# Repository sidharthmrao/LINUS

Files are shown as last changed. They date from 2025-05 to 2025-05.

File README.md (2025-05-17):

# LINUS
“Linus” is a 2D-drawing machine which uses a marker to draw inputted images in the one-line-drawing art style!  
  
[Project Website](https://sidharthmrao.github.io/LINUS/index.html)  
  
### Directory Structure
#### cad
Contains CAD step files.

#### docs
Contains files for the project website.

#### exp
Contains experimentation files for image processing and pathfinding.

#### input
Contains input images

#### lib
 - graph.py - Contains graph datastructures and algorithms
 - render.py - Tools for Pygame rendering
 - serial_com.py - UART communication between Host device and microcontroller
 - skeleton.py - Image processing and skeletonization
 - slicer.py - Optimal path construction

#### pico
 - Contains files to run on the Raspberry Pi Pico for printer control and communication

#### config.py
 - Configuration file, select input image, activate debug mode, etc.

### Running Locally
To run locally, create a Python 3.13 environment using the `requirements.txt`.  
Edit `config.py` as necessary.   
Source it and then run `main.py`.

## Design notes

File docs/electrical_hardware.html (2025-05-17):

LINUS Slicer Electrical Hardware Mechanical Hardware Project Repo (https://github.com/sidharthmrao/LINUS)

LINUS - Microcontrollers (ECE 4760) Final Project - Electrical

# System Overview

Electrically, the system was comprised of six parts:

- 1 Raspberry Pi
- 1 Pico
- 2 Stepper Motor Drivers
- 2 Stepper Motor

Information travels mostly in one direction, from the Pi to the motors, except for the duplex line between the Pico and Pi. We designed our system to minimize interconnectivity in order to make debugging and integration easier. For example, we chose stepper motors because they could do open-loop position control very precisely.

# System Diagram

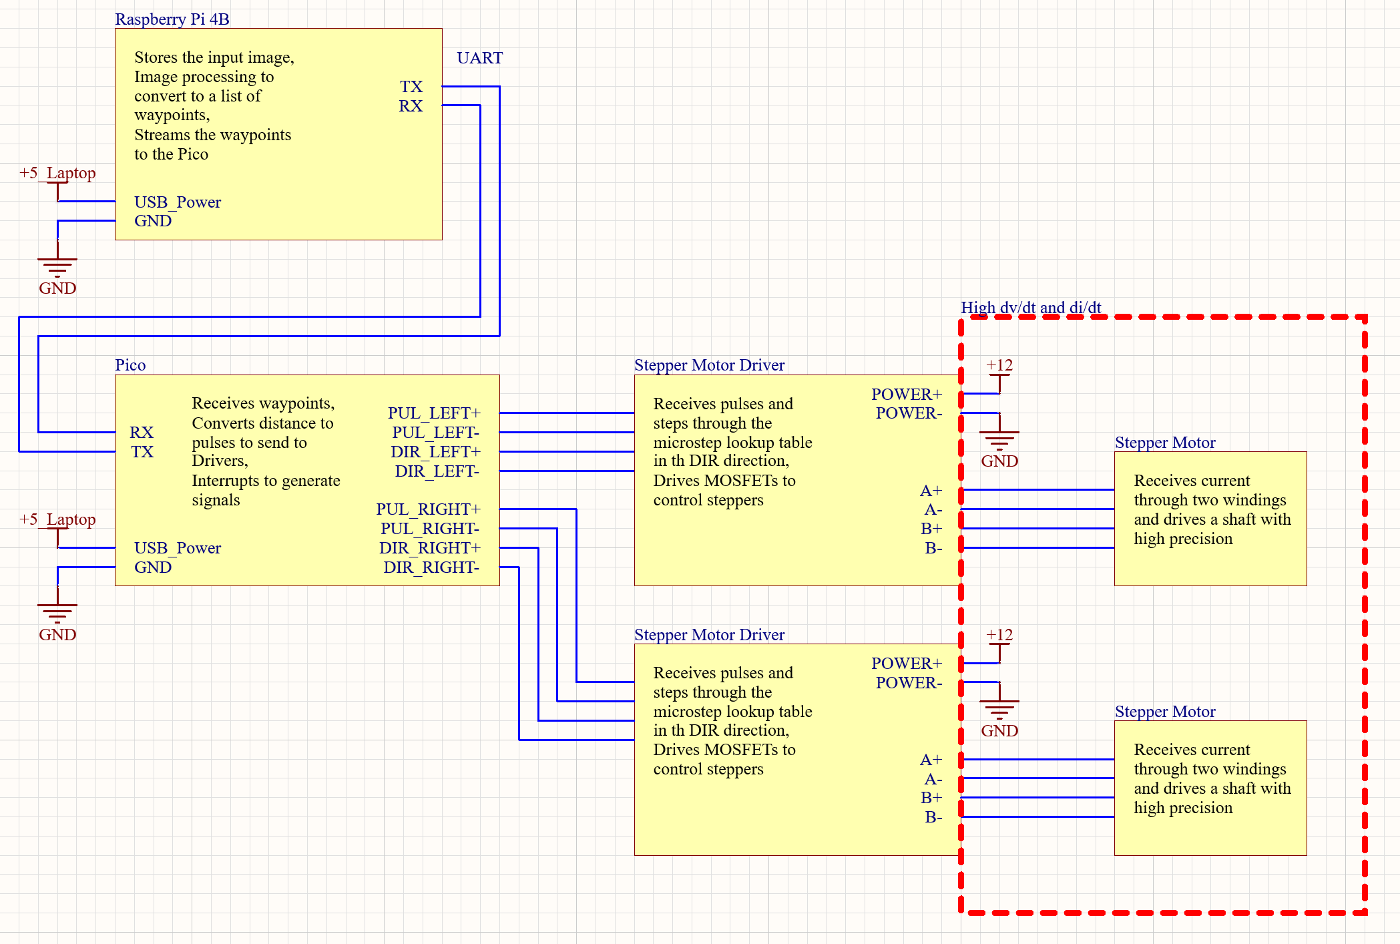
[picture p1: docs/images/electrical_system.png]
Electrical System Schematic of LINUS


# Detailed Technical Description

## Raspberry Pi

LINUS starts at the Pi. Here, the input image is stored and input into the slicer. The slicer takes the image and processes it to create a list of waypoints stored as pixel values on a 480x480 grid. Details about how the Pi turns a general image file into this list can be found in Slicer page.

This list of waypoints represents a list of position setpoints for the stepper motors to get to. The waypoints are densely populated along the planned path so that there is a small distance between each waypoint. This small level of subdivision allows us to paint smooth curves with the stepper motors.

### UART Communication

Now that the Pi has the list of waypoints to send to the Pico, it opens up a serial communication connection with the pico. UART is a full-duplex communication protocol that uses a TX, RX, and GND line to send bits between two devices. UART doesn't use a controller-peripheral architecture, unlike other common communication protocols such as I2C, SPI, and CAN. The Pi and Pico can communicate with each other independently. In our system, we sent strings over UART and parsed them on the receiving end.

Once the UART line is up, we poll the RX line on the Pi to see if the Pico has sent a “READY” string, signaling that it is capable of receiving and executing a waypoint. If so, the Pi will send a waypoint “(X, Y)” over to the Pico. It will then continue polling the line until either the Pico sends “READY” again or the Serial object disconnects.

For debugging purposes, the Pi can also generate an animation of how the Pico would draw the list of waypoints through a pygame window.

## Pico

The Pico is responsible for receiving waypoints from the Pi and outputting PUL and DIR signals to the two stepper motor drivers to move the motors. In this project, we decided to use stepper motors and open-loop control for simplicity in design.

The pico stores two stepper motor structs that store information about configuration (max velocity, GPIO pins) and current state (current position, target position, current velocity).

### Core 1

This core is responsible for communication with the Pi. We needed to use both cores because we have interrupts that generate pulses to the stepper motor driver, and each pulse is generated by one interrupt call. Since our high-precision application required microstepping, we would send thousands of pulses per second to the stepper motor drivers, which would be interrupted by UART writes and reads.

The core begins by initializing the UART peripheral and the motor target positions. Each motor controls movement along one axis, so one motor gets one setpoint along the x-axis, and the other motor gets a setpoint along y.

Then, the core enters its main loop, where it will continuously poll both motors' current and target positions. When one motor reaches its target position, the core will write “READY” to the UART line, signaling to the Pi that the Pico wants to receive a waypoint. It will then read from its UART RX line for the waypoint “(X, Y)” and store those values into the targeted positions for the X motor and Y motor.

It will then go back to checking if the motors have reached their target positions and continue the loop.

### Core 0

Core 0 is responsible for interfacing with the stepper motor drivers. In this dual-core architecture, each variable is only written by one core, so there are zero risks of race conditions. We designed the motor structs this way so that we wouldn't have to worry about multithreading debugging, and so that the behavior of one core is completely decoupled from the behavior of the other.

After initializing GPIO and core 1, core 0 jumps into its main loop. Here, the Pico will check if the current position matches the target position for each motor. If not, it will set the DIR pin to its required state, and bring the PUL pin high. If the current position matches the target position, it won’t set the PUL pin high.

After setting the DIR and PUL pins of both motor drivers to their proper states, core 0 will sleep for 5 microseconds. This is the pulse width. The stepper motor drivers use pulse frequency modulation, and this will be covered in depth in the “Stepper Motor Drivers and Stepper Motors” section coming up.

After sleeping for the pulse width, core 0 will check if the PUL pins are high, and if they are, it will set them low and increment the current position of that motor. It will then sleep for 1200 microseconds, which is the distance between the pulses. This means our pulse frequency is actually fixed, so we only drive the stepper motors at 0, - max_velocity, or +max_velocity.

### The Beauty + Importance of System Simplicity

While it might seem crude to make a system that only drives at three speeds, this was the simplest option out of the many that we successfully implemented. We originally had a system that would generate pulses using interrupts. Each interrupt call would set its own hardware alarm timer to a specific value depending on the desired motor speed (proportional to pulse frequency). This would allow us to drive both motors at different speeds, and we could precisely control the speed.

We also implemented acceleration clamps, which would prevent the motor from accelerating too quickly and slow down the motor as it approached a waypoint. We did this because we wanted a smooth motion through waypoints, and we were concerned that the momentum of the rails would cause the stepper motors to stall when accelerating.

As we tested the system, we raised the acceleration clamps higher and higher until they were functionally not doing anything. Even if the motors instantaneously went from 0 to maximum speed, they still didn't stall, so we removed the code.

Since the motors didn't need the acceleration clamps, they only needed to be able to drive at three speeds. We thus removed those features and the interrupts as well, and rewrote the software in a simpler fashion to improve long-term maintainability and readability, especially since this code may be public for others to read after our project is published.

## Stepper Motor Drivers and Stepper Motors

The Stepper Motor Drivers receive data signals to move from the Pico, and output power signals to the motors to move them. The driver needs two pins to do this: PUL and DIR. DIR will tell the driver which way to turn the motor, and PUL will tell the driver to step once in the DIR direction. We can decide the microstepping resolution of the driver and set it to any multiple of two between 1 and 32. Stepper motors have 100 magnetic poles or 50 pole-pairs on the rotor. They also have two independent windings in the stator that control the rotor.

If you can only drive each winding off, full in one direction, and full in the other direction (with an H-bridge), then you are full-stepping. The full-stepping resolution of a stepper motor is 200 steps per revolution. By microstepping, you drive one winding at less-than-full voltage by PWM-ing on the H-bridge.

The stepper motor driver is able to do a microstepping resolution of 32, which allows us to do 200 * 32 = 6400 pulses per revolution. Internally, the stepper motor driver does this by storing an array 6400 elements long called the microstep lookup table. Each time a falling edge is detected on the PUL input line, the driver increments through the lookup table some amount. If the microstepping resolution is 32, then the driver will increment one position through the array. If the microstepping resolution is 1, then the drive will increment 32 positions through the array. The array contains the PWM duty cycle of the A and B windings. This value gets scaled by the motor drive strength, and then that value is directly sent to the PWM module and gate drivers of the MOSFETs. The DIR pin decides which direction the driver should step through its lookup table.

Changing the PWM duty cycles of the A and B windings of the motor will change the amount of current traveling through them. This modulates the direction of the magnetic field that the rotor sees, and if the rotor’s own permanent magnet field is not aligned with the stator windings' field, then a torque will be applied to the shaft to move it to where the windings want the rotor to be.

Each time the PUL pin is pulsed, the stators magnetic field changes by some position. If the PUL pin is not pulsed, the winding currents will not change, and the rotor will remain in its place. By sending pulses at a specific frequency, the magnetic field position will change at a specific rate. This means that if we control the driver using PFM, then the PFM is modulating the motor's speed, which is very different from other motor applications, where the current is modulating the motor's torque. This unique feature of stepper motors allows us do open-loop position control with very high precision. 6400 pulses per revolution means we can move LINUS's pen with a precision of <0.001 inches.

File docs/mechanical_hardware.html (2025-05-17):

LINUS Slicer Electrical Hardware Mechanical Hardware Project Repo (https://github.com/sidharthmrao/LINUS)

LINUS - Microcontrollers (ECE 4760) Final Project - Mechanical Hardware

# Mechanical Design

The mechanical design for LINUS was largely inspired by the structure of low-cost 3D printers. We chose a belt drive system for its simplicity, affordability, and ease of implementation. The core frame is constructed using two aluminum T-slot extrusions: one 40x20mm and one 20x20mm. The 40x20 T-slot serves as the main X-axis rail, along which the 20x20 T-slot (Y-axis) is mounted. The drawing head (pen holder) moves along the Y-axis, enabling the machine to reach any point within its working area.

Motion in both axes is powered by stepper motors driving timing belts. On each axis, the belt loops through the central slot in the T-slot rail, connecting to a motor pulley at one end and an idler pulley at the other. The idler pulley maintains belt tension and alignment to prevent skipping. Getting the belt routing and tensioning system to work reliably required several rounds of iteration.

## Mechanical Components

X-axis Mounting Plate (motor)
This component anchors the X-axis stepper motor. The motor bolts to the vertical plate, while the 40x20 T-slot rail fits into the rectangular cutout and is secured in place via bolts. This sliding mount allows for adjustable belt tensioning by loosening the blots, shifting the assembly outward, and then re-tightening.

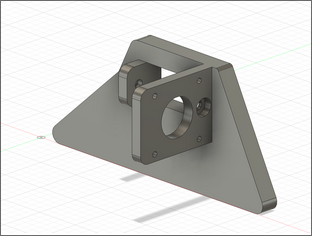
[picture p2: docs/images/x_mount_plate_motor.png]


X-axis Mounting Plate (motor)

X-axis Mounting Plate (idler pulley)
This is the matching plate on the opposite side of the X-axis. It houses the idler pulley, implemented as a bearing press-fit into the mount. The T-slot rail passes through just like on the motor side, and the same sliding method can be used to apply tension to the belt.

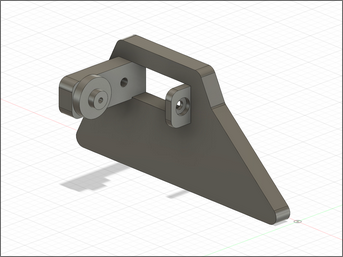
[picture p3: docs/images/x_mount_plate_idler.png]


X-axis Mounting Plate (idler pulley)

Y-axis Mounting Plate (x2)
The two identical plates support the Y-axis rail and connect it to the X-axis motion system. These plates mount to and sandwich the Y-axis rail as well as the bearings or wheels that allow it to slide along the X-axis. This provides smooth motion and stability for the Y-axis rail. Additionally, the belt is routed through the rectangular slots in these plates and glued down to secure it.

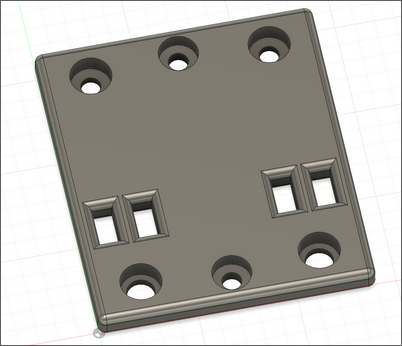
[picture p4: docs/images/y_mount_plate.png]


Y-axis Mounting Plate

Y-axis Motor Mount
This mount holds the Y-axis stepper motor in place and aligns its shaft with the belt path. Like the X-axis motor mount, it attaches to the 20x20 T-slot rail and allows for belt tensioning through a simple sliding mechanism.

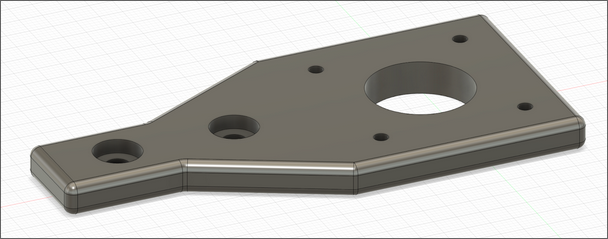
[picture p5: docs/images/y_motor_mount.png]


Y-axis Motor Mount

Y-axis Idler Pulley Mount
Located on the opposite end of the Y-axis rail, this mount holds the idler pulley bearing. It works just like the X-axis version, with a press-fit bearing and a sliding design to adjust tension as needed.

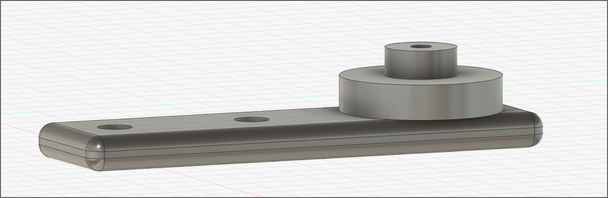
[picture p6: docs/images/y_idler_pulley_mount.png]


Y-axis Idler Pulley Mount

Idler Pulley Half (x2)
These circular components complete the idler pulley assemblies. They press-fit onto the other side of the bearing (the side not already fitted onto the axes), This forms a low-friction guide with an outer lip to prevent the belt from slipping off.

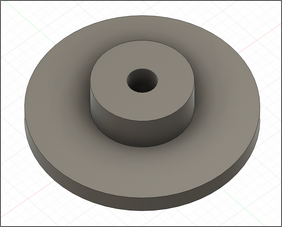
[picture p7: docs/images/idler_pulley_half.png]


Idler Pulley Half

Pen Holder
The pen holder grips the drawing tool (marker) and is mounted to the Y-axis carriage, which in turn moves along the X-axis. It includes a set screw to hold the marker firmly in place while minimizing play. The holder also serves as a termination point for the Y-axis belt, using the same slot and glue strategy described for the Y-axis mounting plate.

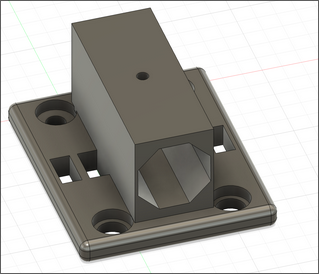
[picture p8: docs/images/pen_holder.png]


Pen Holder

## Design challenges

While developing the mechanical system, we ran into several issues that required redesigns or significant rework.

Unstable Y-axis
Our original mounting approach lacked rigidity, causing the Y-axis to tilt as the weight distribution changed when the pen moved from one side of the axis to the other. This caused the marker to lift from the paper when we didn’t want it to. In order to fix this problem we added a lower plate to sandwich the Y-axis plate. That’s why there are two Y-axis mounting plates.

Belt Skipping
Without proper tension, the belts occasionally skipped teeth on the pulleys, leading to inaccuracies in the drawing. This was especially a problem at higher motor speeds. This was solved by integrating half of the idler pulley assembly into the axes mounts. This prevented the pulley from slipping and causing the belt to skip.

Poor Belt Fastening
The original design plan was to secure the belts with zip ties after looping it through the slots in the mounting plates. However, there wasn’t enough room in the T-slot rails to make this feasible without creating a lot of unnecessary friction. As a result we decided to glue them down, making a less pretty but more functional design.

T-slot vs V-slot Rails
We built the system using T-slot aluminum extrusions, primarily because we weren’t initially aware of V-slot rails. V-slots rails are specifically designed for smoother motion, as their shape naturally guides V-groove wheels along a consistent path. While the T-slot rails ultimately worked, they required more effort to get right. Since T-slots don’t inherently contain wheel tracking, we had to make careful design adjustments to ensure the wheels aligned properly and rolled smoothly along the rails.

Shifting and Instability During Motion
Abrupt movements, especially when changing direction quickly - would sometimes cause the entire device to slide slightly. Since the machine and the paper were not rigidly connected this meant the device could shift while the paper stayed in place, ruining the alignment of the drawing. To solve this, we added a large cardboard base underneath the machine and taped the paper directly to it. This way, any motion would cause both the device and the paper to shift together, preserving relative positioning and improving drawing consistency.

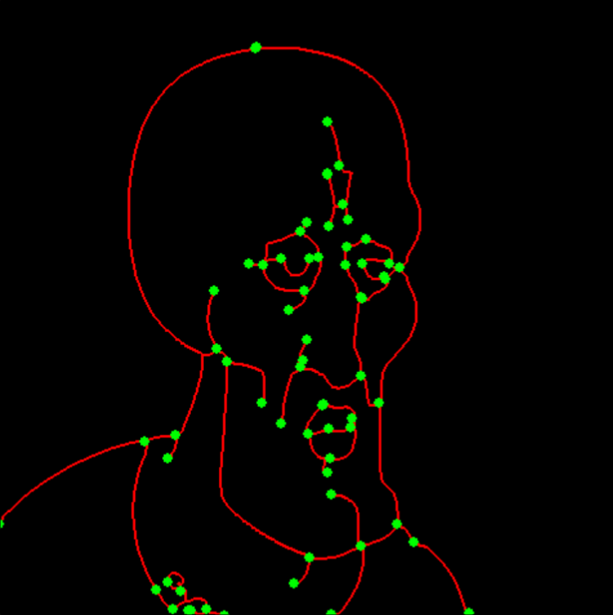
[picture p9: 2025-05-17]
docs/images/subgraph.png

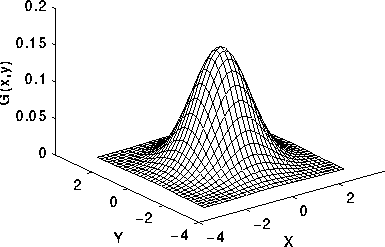
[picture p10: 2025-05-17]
docs/images/gaussian_filter.png

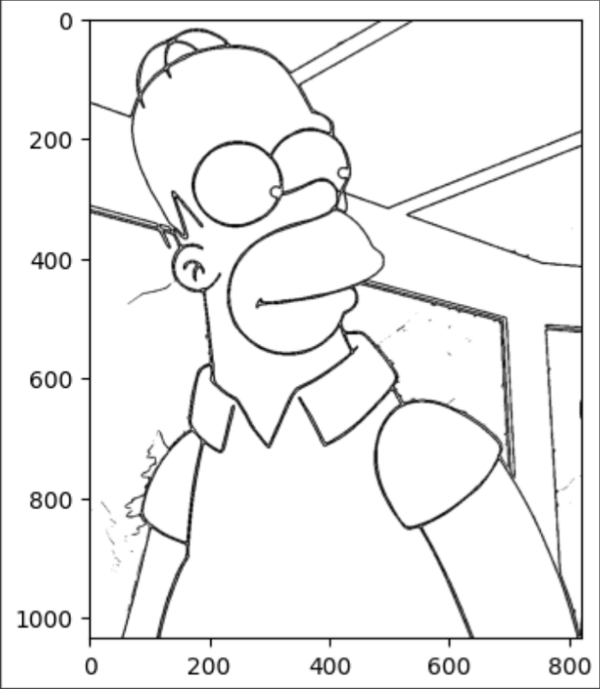
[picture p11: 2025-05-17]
docs/images/our_edge.png

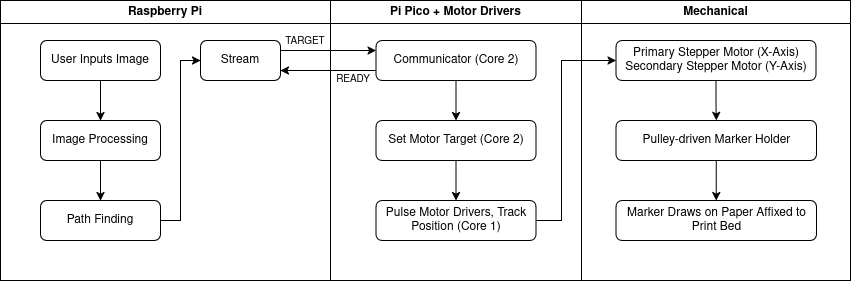
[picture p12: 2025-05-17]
docs/images/system_diagram.png

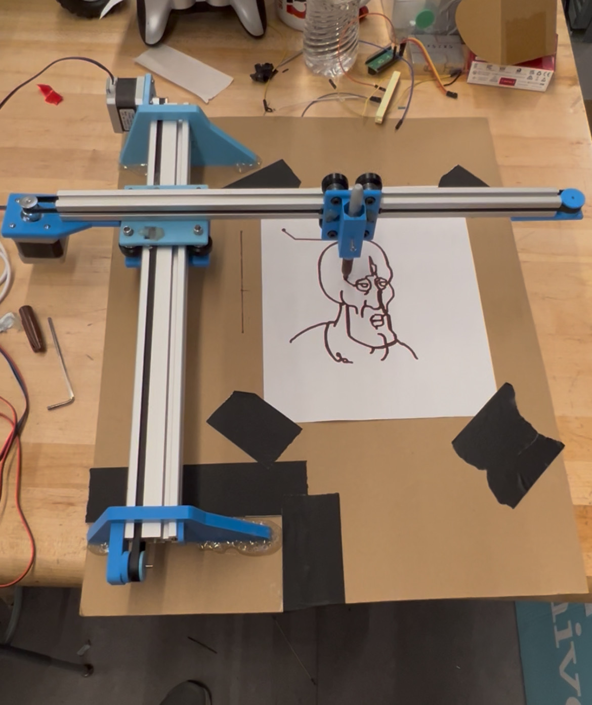
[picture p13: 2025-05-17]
docs/images/project.jpg

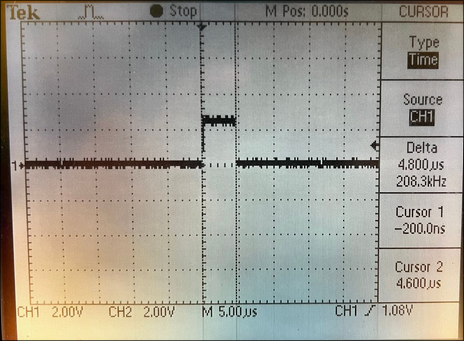
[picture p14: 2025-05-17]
docs/images/pulse_small.png

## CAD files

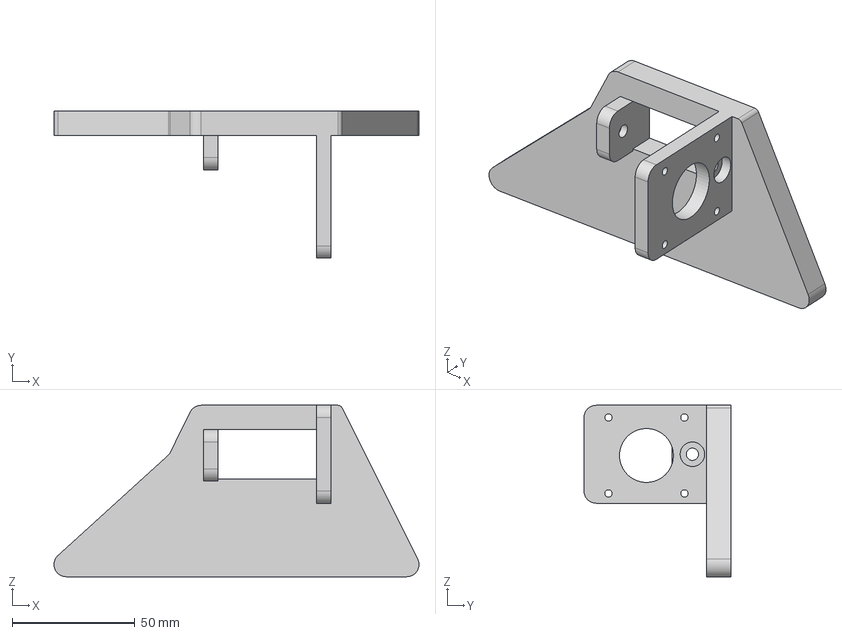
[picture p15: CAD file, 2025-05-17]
cad/microcontrollers_mounting_plate_1.step
149.0 x 60.0 x 70.0 mm

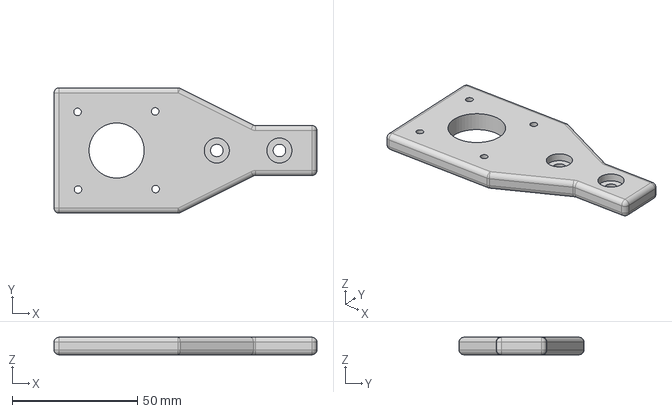
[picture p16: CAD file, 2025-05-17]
cad/x-axis-motor-mount.step
105.0 x 50.0 x 7.00 mm

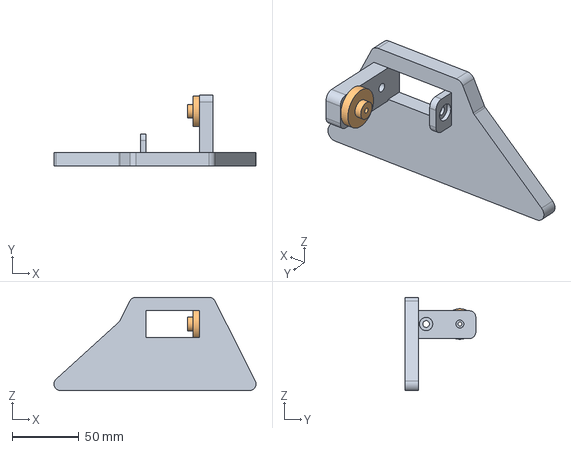
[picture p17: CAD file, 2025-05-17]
cad/microcontrollers_mounting_plate_2.step
151.6 x 53.0 x 70.0 mm

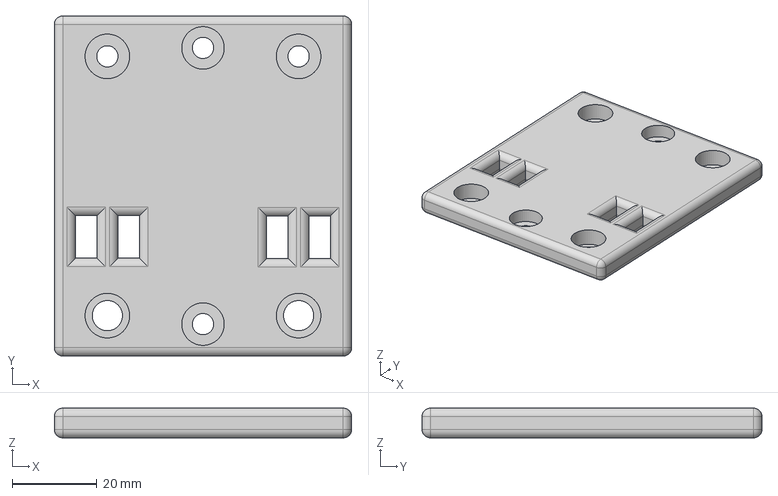
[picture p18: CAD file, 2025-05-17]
cad/x-mounting-plate.step
70.0 x 80.0 x 7.00 mm

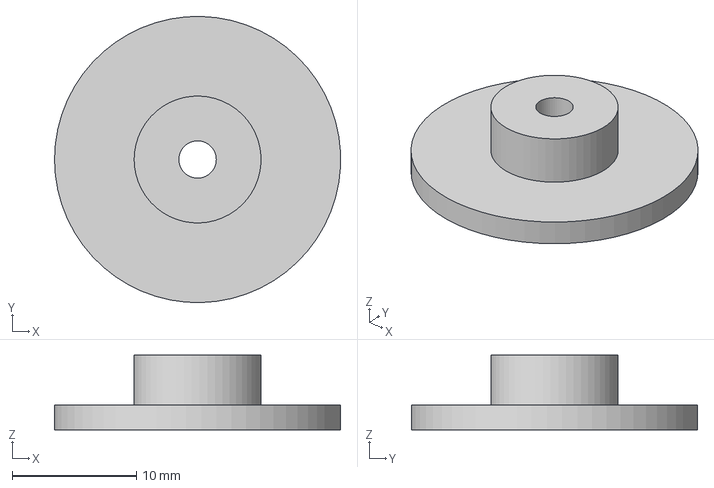
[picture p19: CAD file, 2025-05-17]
cad/idler_pulley_insert.step
23.0 x 23.0 x 6.00 mm

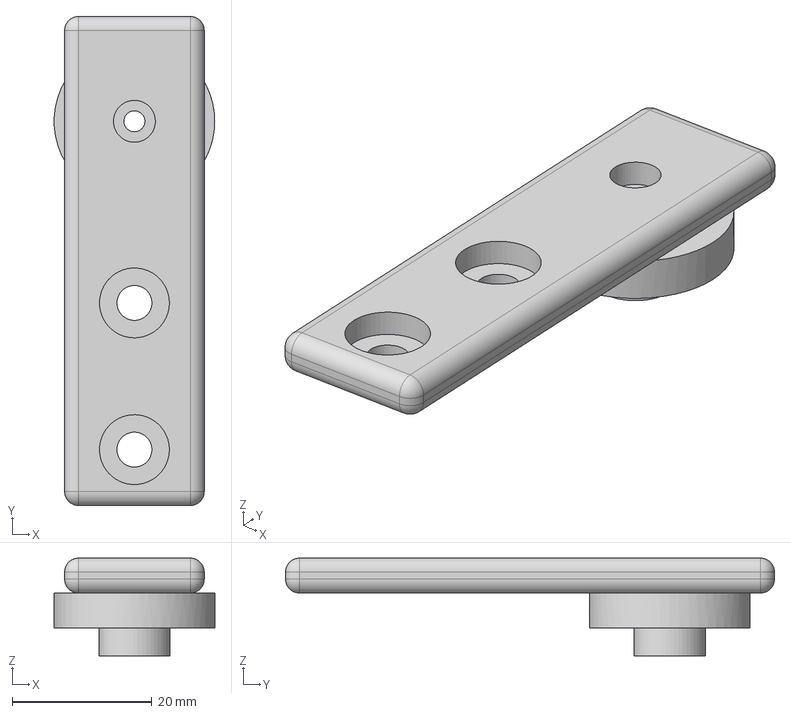
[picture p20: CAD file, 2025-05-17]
cad/x-axis-idler-mount.step
23.0 x 70.0 x 14.0 mm

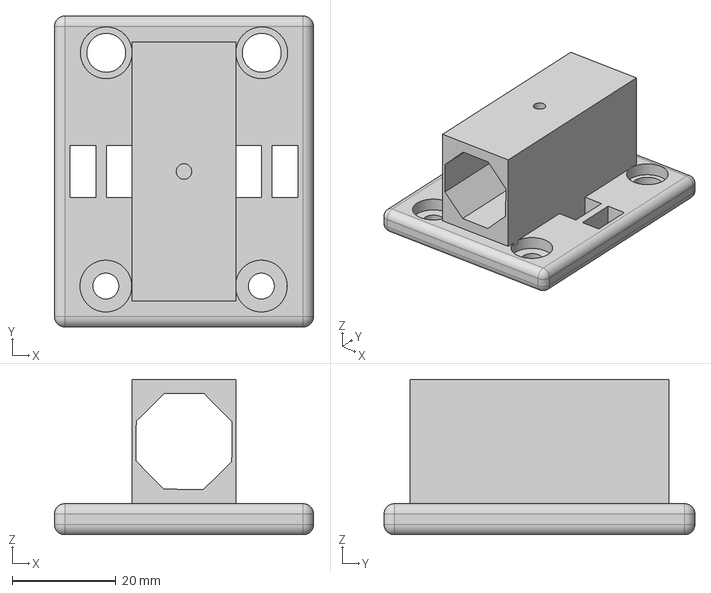
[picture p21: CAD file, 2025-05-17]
cad/pen_holder.step
50.0 x 60.0 x 30.0 mm

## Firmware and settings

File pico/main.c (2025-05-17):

#include "pico/stdlib.h"

#include "hardware/pwm.h"
#include "hardware/irq.h"
#include "hardware/uart.h"

#include "pico/multicore.h"
#include <stdlib.h>
#include <stdio.h>

#include "motor.h"
#include "target.h"

#define WRAPVAL 5000
#define CLKDIV 25.0f

#define LED_PIN 25

#define X_AXIS_IN_PER_ROT (M_PI * .53)
#define X_AXIS_TOTAL_IN 16
#define X_AXIS_TOTAL_UNITS 100
#define X_AXIS_ROT_PER_UNITS .096 // ((X_AXIS_TOTAL_IN / X_AXIS_TOTAL_UNITS) / X_AXIS_IN_PER_ROT)

StepperMotor motor_x = {
    .STEP_PIN = 18,
    .DIR_PIN = 2,
    .EN_PIN = 6,
    .last_target_position = 0,
    .current_position = 0,
    .target_position = 0,
    .velocity_rps = 0,
    .max_velocity_rps = .5,
    .max_acceleration = 5.0,
    .flipped = false};

StepperMotor motor_y = {
    .STEP_PIN = 16,
    .DIR_PIN = 3,
    .EN_PIN = 7,
    .last_target_position = 0,
    .current_position = 0,
    .target_position = 0,
    .velocity_rps = 0,
    .max_velocity_rps = .5,
    .max_acceleration = 5.0,
    .flipped = false};

void core1_main()
{
    init_uart();

    set_target_position(&motor_x, &motor_y, 0.0, 0.0); // 50.0 * X_AXIS_ROT_PER_UNITS

    // Current time in microseconds
    uint32_t current_time = time_us_32();
    uint32_t last_time = current_time;

    while (current_time - last_time < 3000000)
    {
        current_time = time_us_32();
    }

    while (true)
    {
        // bool left_motor_reached_mid = false;
        // bool right_motor_reached_mid = false;

        // int mid_position_x = (motor_x.target_position - motor_x.last_target_position) / 2 + motor_x.last_target_position;
        // int mid_position_y = (motor_y.target_position - motor_y.last_target_position) / 2 + motor_y.last_target_position;

        // bool direction_x = (motor_x.target_position - motor_x.last_target_position) > 0;
        // bool direction_y = (motor_y.target_position - motor_y.last_target_position) > 0;

        // // While both motors have not gone beyond halfway point
        // while (!left_motor_reached_mid || !right_motor_reached_mid)
        // {
        //     if (motor_x.current_position >= mid_position_x && direction_x)
        //     {
        //         left_motor_reached_mid = true;
        //     }
        //     else if (motor_x.current_position <= mid_position_x && !direction_x)
        //     {
        //         left_motor_reached_mid = true;
        //     }

        //     if (motor_y.current_position >= mid_position_y && direction_y)
        //     {
        //         right_motor_reached_mid = true;
        //     }
        //     else if (motor_y.current_position <= mid_position_y && !direction_y)
        //     {
        //         right_motor_reached_mid = true;
        //     }
        // }

        while (motor_x.current_position != motor_x.target_position || motor_y.current_position != motor_y.target_position)
        {
        }

        float x, y;

        // When the motor hits its target position, it's ready to receive a new target
        printf("READYREADYREADYREADY\n");

        bool target = receive_target_position(&x, &y);

        if (target)
        {
            // printf("Target position: (%f, %f)\n", x, y);
            set_target_position(&motor_x, &motor_y, x, y);
        }
    }
}

// Main (runs on core 0)
int main()
{
    stdio_init_all();

    // Init pins for both stepper motors
    StepperMotor *motors[] = {&motor_x, &motor_y};
    for (int i = 0; i < 2; i++)
    {
        StepperMotor *m = motors[i];

        // After some testing, I found that the Stepper motor steps on the
        // falling edge of PUL+, so initialize it high and pulse it low.
        gpio_init(m->STEP_PIN);
        gpio_set_dir(m->STEP_PIN, GPIO_OUT);
        gpio_put(m->STEP_PIN, 1);

        gpio_init(m->DIR_PIN);
        gpio_set_dir(m->DIR_PIN, GPIO_OUT);
        gpio_put(m->DIR_PIN, 0);

        gpio_init(m->EN_PIN);
        gpio_set_dir(m->EN_PIN, GPIO_OUT);
        gpio_put(m->EN_PIN, 1);
    }

    // Turn on LED to indicate that the program has started
    gpio_init(LED_PIN);
    gpio_set_dir(LED_PIN, GPIO_OUT);
    gpio_put(LED_PIN, 1);

    // start core 1
    multicore_reset_core1();
    multicore_launch_core1(&core1_main);

    // Current time
    uint64_t pulse_width = 5;
    uint64_t pulse_delay = 600;

    bool pulse_high = false;

    while (true)
    {
        if (pulse_high)
        {
            for (int i = 0; i < 2; i++)
            {
                StepperMotor *m = motors[i];

                gpio_put(m->STEP_PIN, 0); // Set step pin low

                m->current_position += m->step_direction; // Update the current position
            }

            pulse_high = false;
            sleep_us(pulse_delay); // Wait for the pulse width
        }
        else
        {
            for (int i = 0; i < 2; i++)
            {
                StepperMotor *m = motors[i];

                if (m->current_position < m->target_position)
                {
                    gpio_put(m->DIR_PIN, m->flipped ? 0 : 1); // Set direction pin high
                    m->step_direction = 1;                    // Set step direction to CCW

                    gpio_put(m->STEP_PIN, 1); // Set step pin high
                }
                else if (m->current_position > m->target_position)
                {
                    gpio_put(m->DIR_PIN, m->flipped ? 1 : 0); // Set direction pin low
                    m->step_direction = -1;                   // Set step direction to CW

                    gpio_put(m->STEP_PIN, 1); // Set step pin high
                }
                else
                {
                    m->step_direction = 0;    // Stop stepping
                    gpio_put(m->STEP_PIN, 0); // Set step pin high
                }
            }

            pulse_high = true;
            sleep_us(pulse_width); // Wait for the pulse delay
        }
    }
}

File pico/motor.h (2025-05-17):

#pragma once

#include "pico/stdlib.h"
#include <math.h>

#define MICROSTEP_RESOLUTION 8   // 1/16 microstepping
#define STEPS_PER_REVOLUTION 200 // 1.8 degree stepper motor
#define TICKS_PER_REVOLUTION (STEPS_PER_REVOLUTION * MICROSTEP_RESOLUTION)

#define REVOLUTIONS_PER_UNIT_X 1.0f
#define REVOLUTIONS_PER_UNIT_Y 1.0f

#define TICKS_PER_UNIT_X REVOLUTIONS_PER_UNIT_X *TICKS_PER_REVOLUTION
#define TICKS_PER_UNIT_Y REVOLUTIONS_PER_UNIT_Y *TICKS_PER_REVOLUTION

// Pulse width in microseconds (step pulse duration)
#define STEP_PULSE_WIDTH_US 5

typedef struct
{
    uint STEP_PIN;
    uint DIR_PIN;
    uint EN_PIN;
    volatile int last_target_position;
    volatile int current_position;
    volatile int target_position;
    volatile float velocity_rps; // current speed in rps
    float max_velocity_rps;      // max speed in rps
    float max_acceleration;      // max acceleration in rps/s
    int step_direction;          // direction of rotation (1 for CW, -1 for CCW)
    bool flipped;
    uint64_t last_time_us;
    repeating_timer_t timer;
} StepperMotor;

void set_target_position(StepperMotor *x, StepperMotor *y, float target_x, float target_y)
{
    x->last_target_position = x->target_position;
    y->last_target_position = y->target_position;
    x->target_position = (int)(target_x * TICKS_PER_UNIT_X);
    y->target_position = (int)(target_y * TICKS_PER_UNIT_Y);
}
